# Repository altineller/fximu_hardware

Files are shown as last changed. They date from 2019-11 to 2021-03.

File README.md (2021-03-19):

### fximu_hardware

Hardware files for FXIMU project.

**Project main repository: https://github.com/altineller/fximu**

**Project firmware repository: https://github.com/altineller/fximu_firmware**  

---
|tr000003 |license|
|----|----|

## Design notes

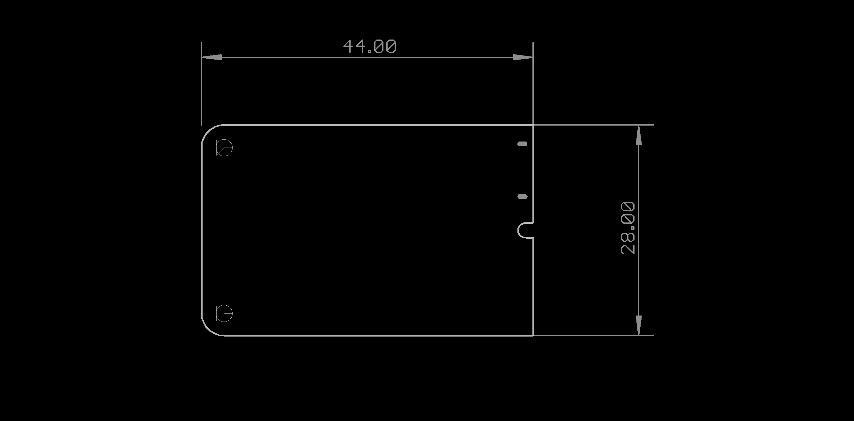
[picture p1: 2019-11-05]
FXIMUv01b/fximu_dimension_diagram.png

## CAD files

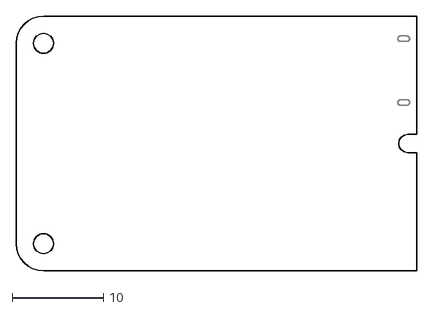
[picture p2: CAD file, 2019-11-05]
FXIMUv01b/FXIMU.dxf
44.0 x 28.0

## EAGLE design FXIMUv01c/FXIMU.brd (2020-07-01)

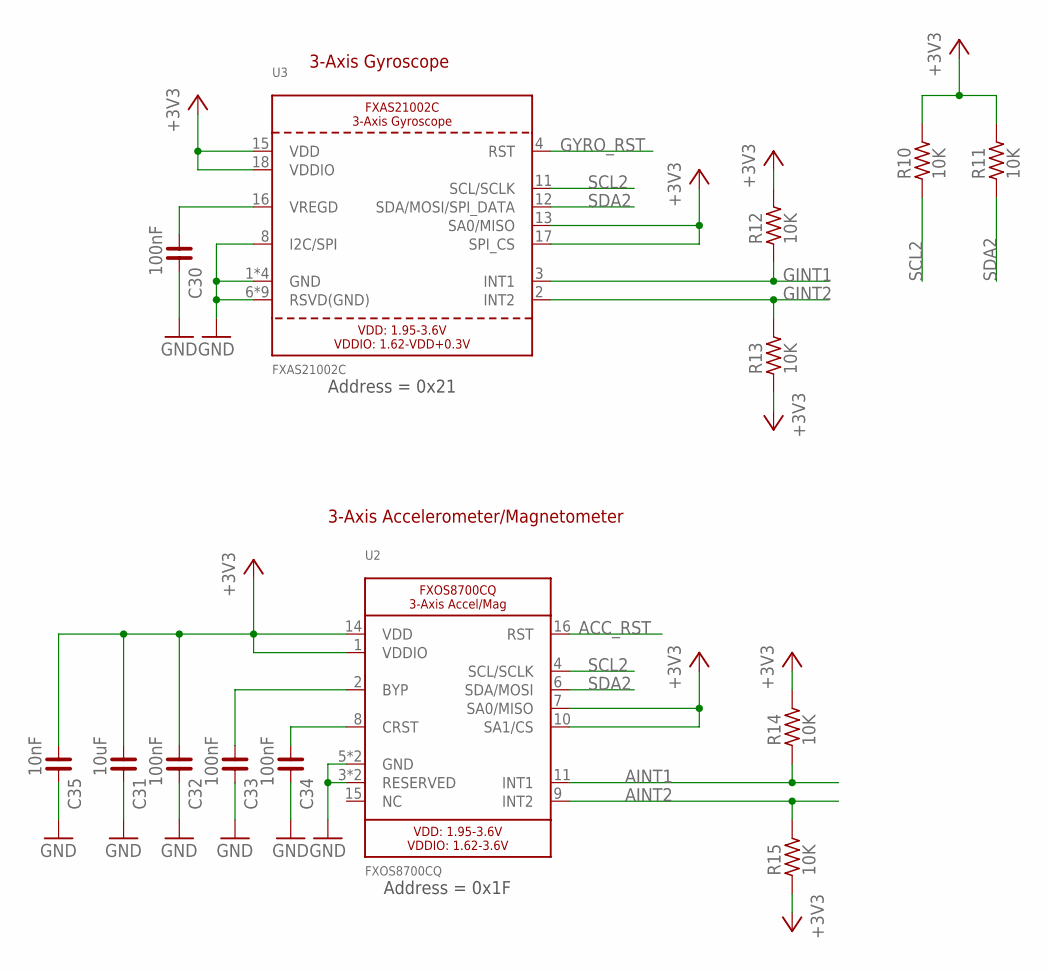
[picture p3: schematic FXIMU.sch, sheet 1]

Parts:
C30, C32, C33, C34: 100nF; C0402
C31: 10uF; C0603
C35: 10nF; C0402
R10, R11, R12, R13, R14, R15: 10K; R0402
U2: FXOS8700CQ; QFN16_3MM_FREESCALE_5X3
U3: FXAS21002C; QFN24_4MM_FREESCALE_7X5

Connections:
+3V3: C31.1, C32.1, C35.1, R10.2, R11.2, R12.2, R13.1, R14.2, R15.1, U2.1 (VDDIO), U2.7 (SA0/MISO), U2.10 (SA1/CS), U2.14 (VDD), U3.13 (SA0/MISO), U3.15 (VDD), U3.17 (SPI_CS), U3.18 (VDDIO); also elsewhere on the board
ACC_RST: U2.16 (RST); also elsewhere on the board
AINT1: R14.1, U2.11 (INT1); also elsewhere on the board
AINT2: R15.2, U2.9 (INT2); also elsewhere on the board
GINT1: R12.1, U3.3 (INT1); also elsewhere on the board
GINT2: R13.2, U3.2 (INT2); also elsewhere on the board
GND: C30.2, C31.2, C32.2, C33.2, C34.2, C35.2, U2.3 (RESERVED), U2.5 (GND), U2.12 (GND), U2.13 (RESERVED), U3.1 (GND), U3.5 (GND), U3.6 (RSVD(GND)), U3.7 (RSVD(GND)), U3.8 (I2C/SPI), U3.9 (RSVD(GND)), U3.10 (RSVD(GND)), U3.14 (GND), U3.19 (GND), U3.20 (RSVD(GND)), U3.21 (RSVD(GND)), U3.22 (RSVD(GND)), U3.23 (RSVD(GND)), U3.24 (RSVD(GND)); also elsewhere on the board
GYRO_RST: U3.4 (RST); also elsewhere on the board
unnamed: C30.1, U3.16 (VREGD)
unnamed: C33.1, U2.2 (BYP)
unnamed: C34.1, U2.8 (CRST)
SCL2: R10.1, U2.4 (SCL/SCLK), U3.11 (SCL/SCLK); also elsewhere on the board
SDA2: R11.1, U2.6 (SDA/MOSI), U3.12 (SDA/MOSI/SPI_DATA); also elsewhere on the board

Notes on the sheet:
Address = 0x21
Address = 0x1F
3-Axis Accelerometer/Magnetometer
3-Axis Gyroscope

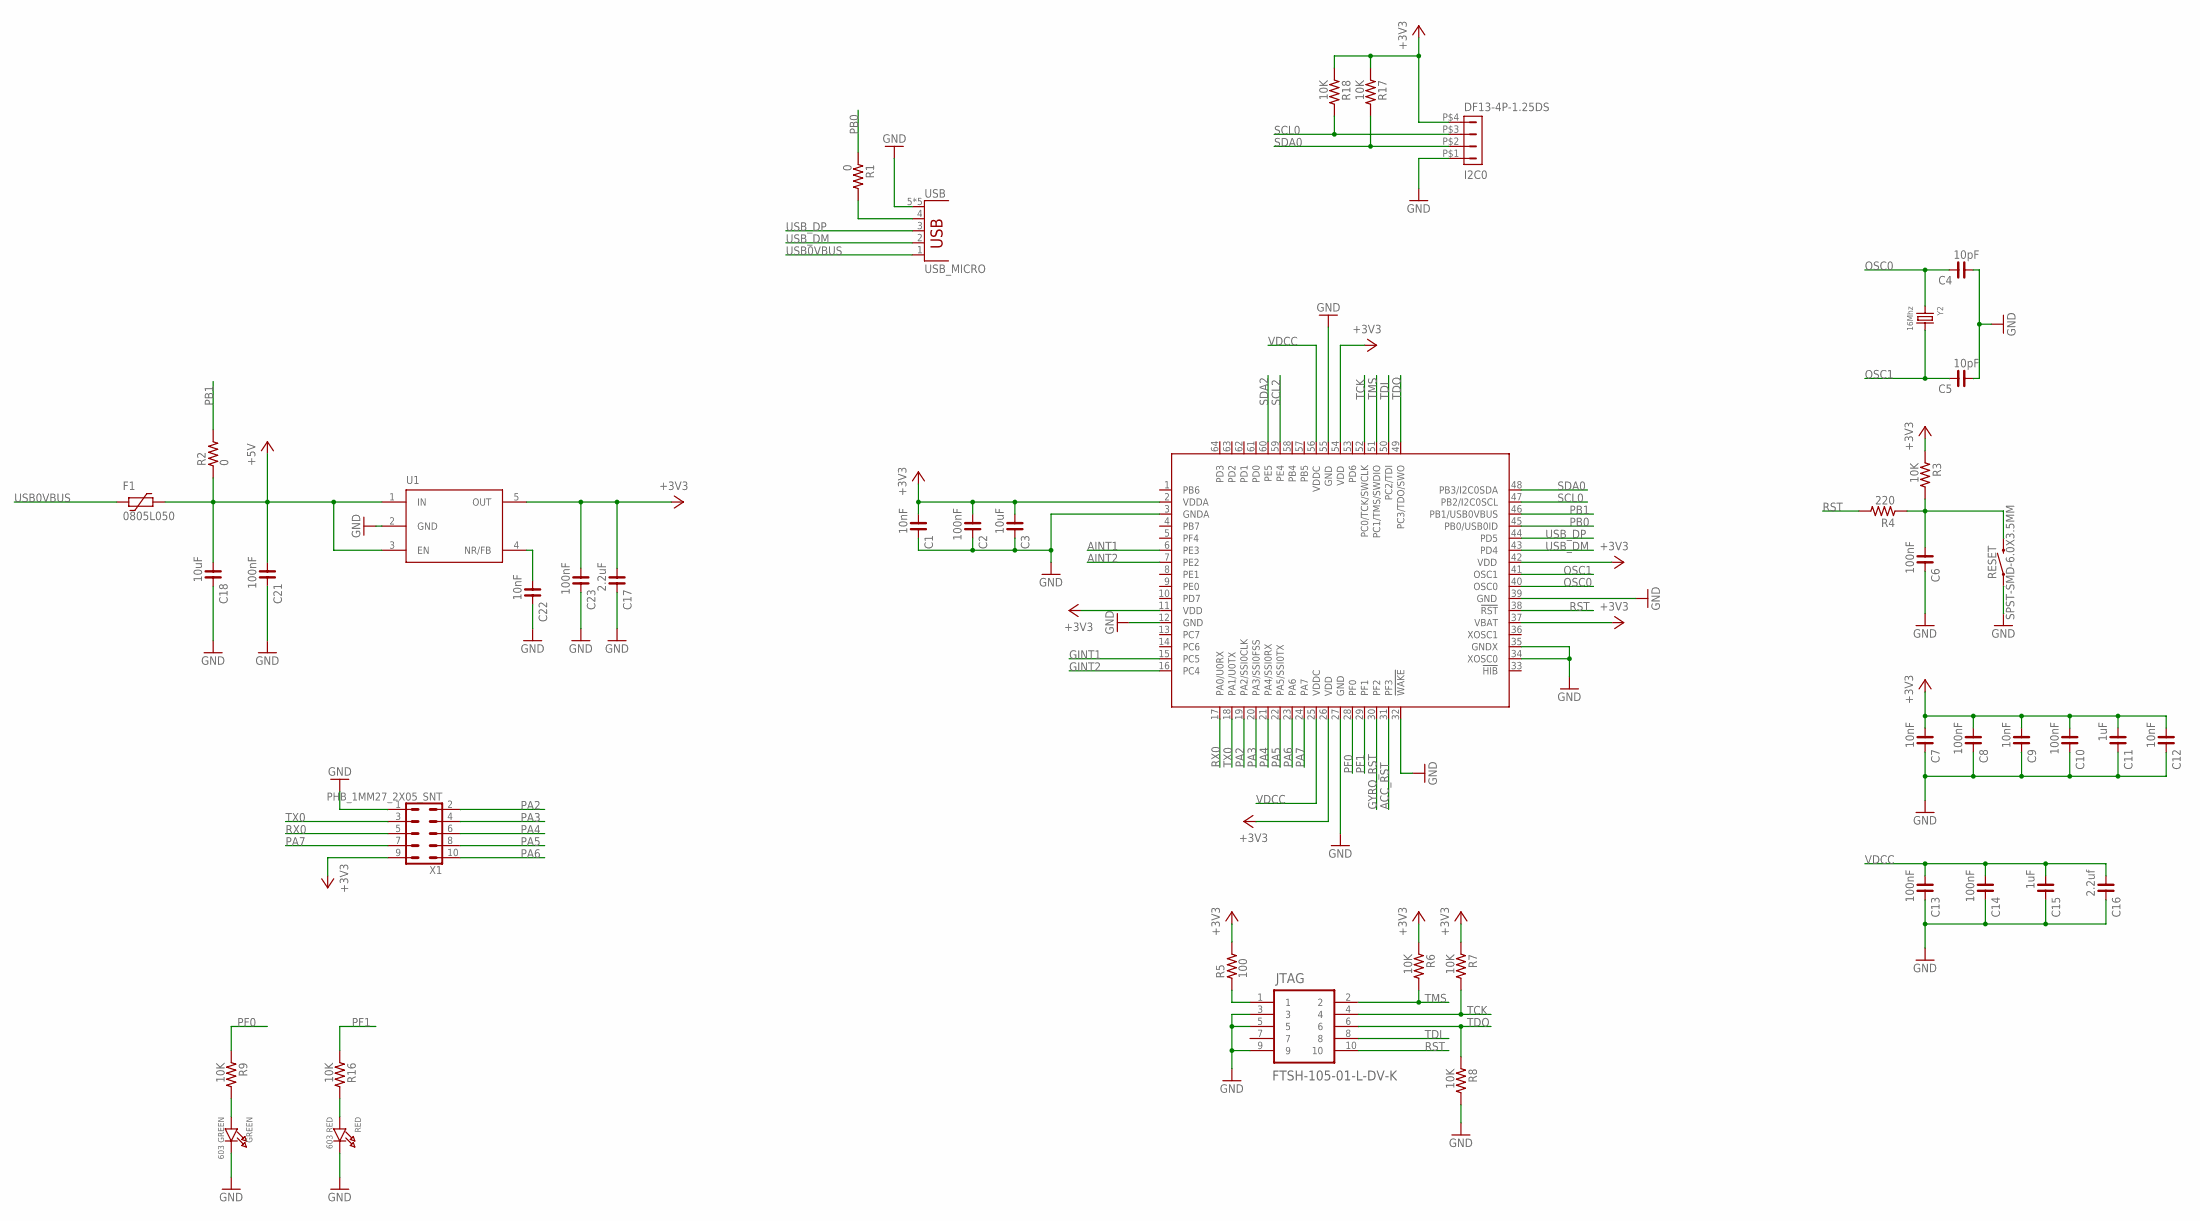
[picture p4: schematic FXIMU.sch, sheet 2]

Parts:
C1, C7, C9, C12, C22: 10nF; C0402
C2, C6, C8, C10, C13, C14, C21, C23: 100nF; C0402
C3, C18: 10uF; C0603
C4, C5: 10pF; C0402
C11, C15: 1uF; C0402
C16: 2.2uf; C0603
C17: 2.2uF; C0603
F1: 0805L050; 0805L
GREEN: 603 GREEN; CHIPLED_0603
I2C0: DF13-4P-1.25DS
IC1: TM4C123[7,G]XXPM; PM_S-PQFP-G64
JTAG: FTSH-105-01-L-DV-K; SAMTEC_FTSH-105-01-L-DV-K
R1, R2: 0; R0402
R3, R6, R7, R8, R9, R16, R17, R18: 10K; R0402
R4: 220; R0402
R5: 100; R0402
RED: 603 RED; CHIPLED_0603
RESET: SPST-SMD-6.0X3.5MM; TACTILE_SWITCH_SMD_6.0X3.5MM
U1: TPS73633; SOT23-5L
USB: USB_MICRO; USB_MICRO_MOLEX_FULL
X1: PHB_1MM27_2X05_SNT
Y2: 16Mhz; 6X3.3MM

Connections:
+3V3: C1.1, C2.1, C3.1, C7.1, C8.1, C9.1, C10.1, C11.1, C12.1, C17.1, C23.1, I2C0.P$4 (4), IC1.2 (VDDA), IC1.11 (VDD), IC1.26 (VDD), IC1.37 (VBAT), IC1.42 (VDD), IC1.54 (VDD), R3.1, R5.2, R6.1, R7.1, R17.1, R18.1, U1.5 (OUT), X1.9; also elsewhere on the board
+5V: C18.1, C21.1, F1.1, R2.1, U1.1 (IN), U1.3 (EN)
ACC_RST: IC1.31 (PF3); also elsewhere on the board
AINT1: IC1.6 (PE3); also elsewhere on the board
AINT2: IC1.7 (PE2); also elsewhere on the board
GINT1: IC1.15 (PC5); also elsewhere on the board
GINT2: IC1.16 (PC4); also elsewhere on the board
GND: C1.2, C2.2, C3.2, C4.1, C5.1, C6.2, C7.2, C8.2, C9.2, C10.2, C11.2, C12.2, C13.2, C14.2, C15.2, C16.2, C17.2, C18.2, C21.2, C22.2, C23.2, GREEN.C, I2C0.P$1 (1), IC1.3 (GNDA), IC1.12 (GND), IC1.27 (GND), IC1.32 (!WAKE), IC1.34 (XOSC0), IC1.35 (GNDX), IC1.39 (GND), IC1.55 (GND), JTAG.3, JTAG.5, JTAG.9, R8.2, RED.C, RESET.1, U1.2 (GND), USB.5 (GND), USB.P$1 (GND), USB.P$2 (GND), USB.P$3 (GND), USB.P$4 (GND), X1.1; also elsewhere on the board
GYRO_RST: IC1.30 (PF2); also elsewhere on the board
unnamed: JTAG.1, R5.1
unnamed: C6.1, R3.2, R4.1, RESET.2
unnamed: GREEN.A, R9.2
unnamed: R1.2, USB.4 (ID)
unnamed: R16.2, RED.A
unnamed: C22.1, U1.4 (NR/FB)
OSC0: C4.2, IC1.40 (OSC0), Y2.1
OSC1: C5.2, IC1.41 (OSC1), Y2.2
PA2: IC1.19 (PA2/SSI0CLK), X1.2
PA3: IC1.20 (PA3/SSI0FSS), X1.4
PA4: IC1.21 (PA4/SSI0RX), X1.6
PA5: IC1.22 (PA5/SSI0TX), X1.8
PA6: IC1.23 (PA6), X1.10
PA7: IC1.24 (PA7), X1.7
PB0: IC1.45 (PB0/USB0ID), R1.1
PB1: IC1.46 (PB1/USB0VBUS), R2.2
PF0: IC1.28 (PF0), R9.1
PF1: IC1.29 (PF1), R16.1
RST: IC1.38 (!RST), JTAG.10, R4.2
RX0: IC1.17 (PA0/U0RX), X1.5
SCL0: I2C0.P$3 (3), IC1.47 (PB2/I2C0SCL), R18.2
SCL2: IC1.59 (PE4); also elsewhere on the board
SDA0: I2C0.P$2 (2), IC1.48 (PB3/I2C0SDA), R17.2
SDA2: IC1.60 (PE5); also elsewhere on the board
TCK: IC1.52 (PC0/TCK/SWCLK), JTAG.4, R7.2
TDI: IC1.50 (PC2/TDI), JTAG.8
TDO: IC1.49 (PC3/TDO/SWO), JTAG.6, R8.1
TMS: IC1.51 (PC1/TMS/SWDIO), JTAG.2, R6.2
TX0: IC1.18 (PA1/U0TX), X1.3
USB0VBUS: F1.2, USB.1 (VBUS)
USB_DM: IC1.43 (PD4), USB.2 (D-)
USB_DP: IC1.44 (PD5), USB.3 (D+)
VDCC: C13.1, C14.1, C15.1, C16.1, IC1.25 (VDDC), IC1.56 (VDDC)

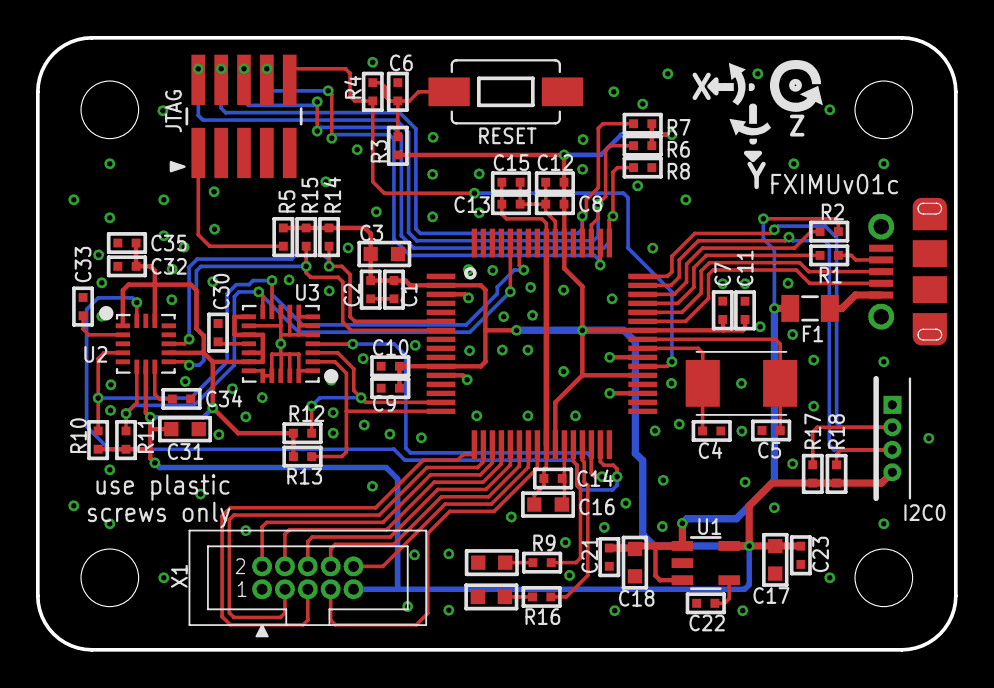
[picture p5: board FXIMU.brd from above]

Board: 2 copper layers, 51.0 x 34.0 mm, 61 parts (0 on the bottom side), 45 nets.

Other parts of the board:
U$27: SYMBOL_GYRO_CCLOCKWISE
U$28: SYMBOL_GYRO_CLOCKWISE
U$31: SYMBOL_GYRO_Z

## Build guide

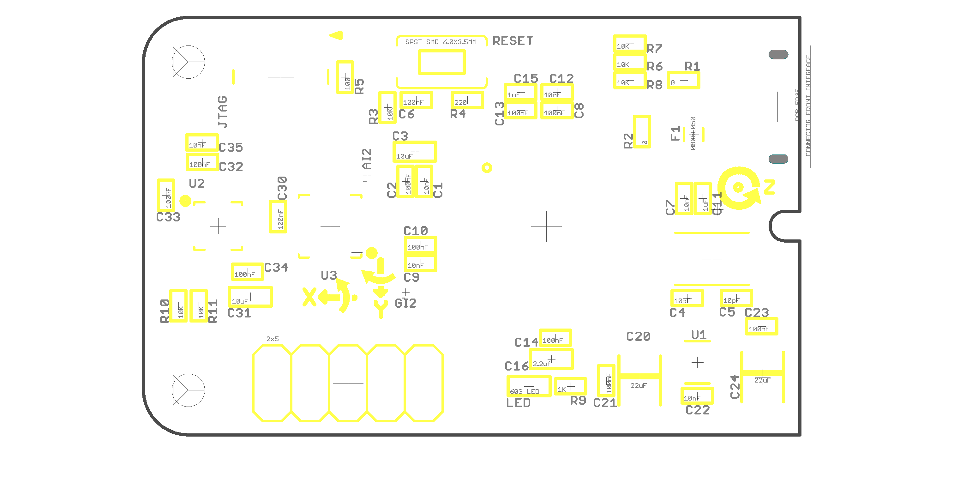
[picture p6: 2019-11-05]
FXIMUv01b/fximu_montage_diagram.png

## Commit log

2020-07-01 fximu v01c eagle files
    [FXIMU.brd, FXIMU.sch]
2020-07-01 Gerber files added
    [FXIMU.GBL, FXIMU.GBO, FXIMU.GBP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]

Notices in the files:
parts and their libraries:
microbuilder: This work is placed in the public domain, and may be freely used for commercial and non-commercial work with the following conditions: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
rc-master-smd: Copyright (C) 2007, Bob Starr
